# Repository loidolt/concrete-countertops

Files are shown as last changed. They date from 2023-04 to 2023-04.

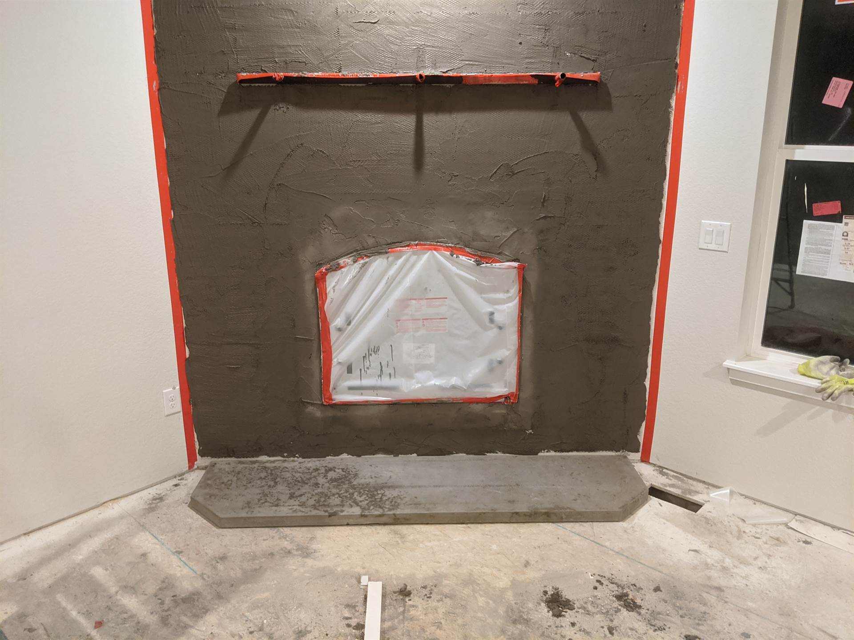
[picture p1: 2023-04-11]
images/ConcreteCountertops (8).jpg

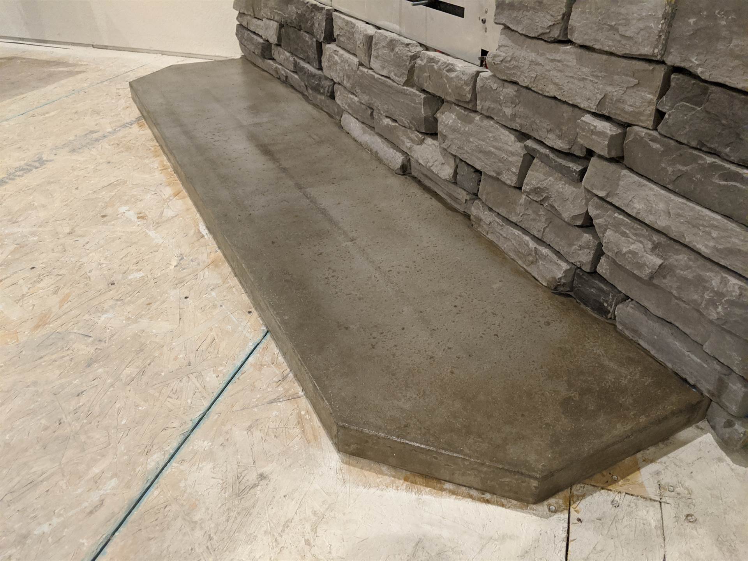
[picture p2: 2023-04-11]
images/ConcreteCountertops (5).jpg

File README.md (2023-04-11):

---
published: true
status: complete
date: 11/17/2019
tags: other, housing
description: The touch and go experience of pouring our entire house's concrete countertops.
slug: concrete-countertops
---

# Concrete Countertops

The touch and go experience of pouring our entire house's concrete countertops.

## Table of Contents

- [Concrete Countertops](#concrete-countertops)
  - [Table of Contents](#table-of-contents)
  - [General Info](#general-info)
  - [Process](#process)
  - [Problems](#problems)
    - [Molds](#molds)
    - [Mix](#mix)
    - [Pouring](#pouring)
  - [Recovery](#recovery)
  - [Finish](#finish)
  - [Technologies](#technologies)

## General Info

When we built our house in Monument, CO, we decided to do concrete countertops because we liked the industrial look and it saved us a lot of money on granite (plus let's be honest, I just like to make stuff.) Pouring our own also allowed us to do some cool stuff like a drain slope section of the kitchen sink area to direct dripping hand water back into the sink.

That said, this project very nearly didn't work out for a few reasons.

## Process

Designing these and making the forms was relatively easy. They are essentially just large rectangles of a specific size with foam knockouts for the sinks and faucets. The foam knockouts were cut on the CNC and were modeled directly from the manufacturer's technical drawings for each item.

Forms were made from melamine and the foam pieces were located and siliconed into place. We also used a silicone round-over kit to create a fillet on the resultant concrete edges.

A rebar substructure was created for each mold and set aside to be placed into each mold after it was half-way filled. Concrete was mixed per the directions on the bag (more on this in the "problems" section) with some fiberglass additive mixed in for edge strength and the molds were poured/packed.

## Problems

Here's the good stuff, also known as "how to not have a terrible time and almost ruin your entire project" as we did.

### Molds

If you need more than one base layer sheet of melamine as we did for the island countertop, be sure to seal the edges of the melamine before assembly, and then seal the joint between pieces after assembly. Failure to do so will result in the edge of the melamine absorbing water and expanding, creating a divot in your finished surface.

Check your knockout placement as many times as you can muster, check it based on the 3d model, check it based on the hardware, and triple-check it based on the real life cabinet layout. We discovered after pouring the island countertop that the sink was a couple of inches too far to one side. We then had to dig up concrete that was already setting and move the knockouts over, not fun.

### Mix

Mix the concrete at least twice as wet as the bag says if you are using Quikrete Concrete Countertop Mix. I know all the guidance for concrete says to mix it as dry as possible for best strength, we aren't trying to build a bridge here, you'll be more than fine in the strength department. If you mix it to the directions on the bag be prepared to do a ton of filling and skim coating to get a smooth surface back.

### Pouring

Pour these one at a time, not all at once as we did. Take your time and use some source of vibration to knock out the air bubbles and settle fines. I also advise not doing this at sunset, in the cold, with just a couple of work lights.

## Recovery

Our countertops came out pretty rough, basically looking like a concrete sponge. Luckily, concrete is pretty forgiving in this aspect since you can apply essentially as many skim coats as your patience allows. So recovery for us was a long process of skimming, sanding, skimming, and sanding.

## Finish

We used Omega Concrete Countertop Sealer to add some toughness and prevent stains. I highly recommend this sealer and would use it again in a heartbeat. Easy to mix and apply durable, and heat resistant. We did find, at least in our climate with the house kept at about 65 degrees, that it took a little longer to set than we expected and it did add a slightly green tinge to the concrete.

## Technologies

- Sketchup

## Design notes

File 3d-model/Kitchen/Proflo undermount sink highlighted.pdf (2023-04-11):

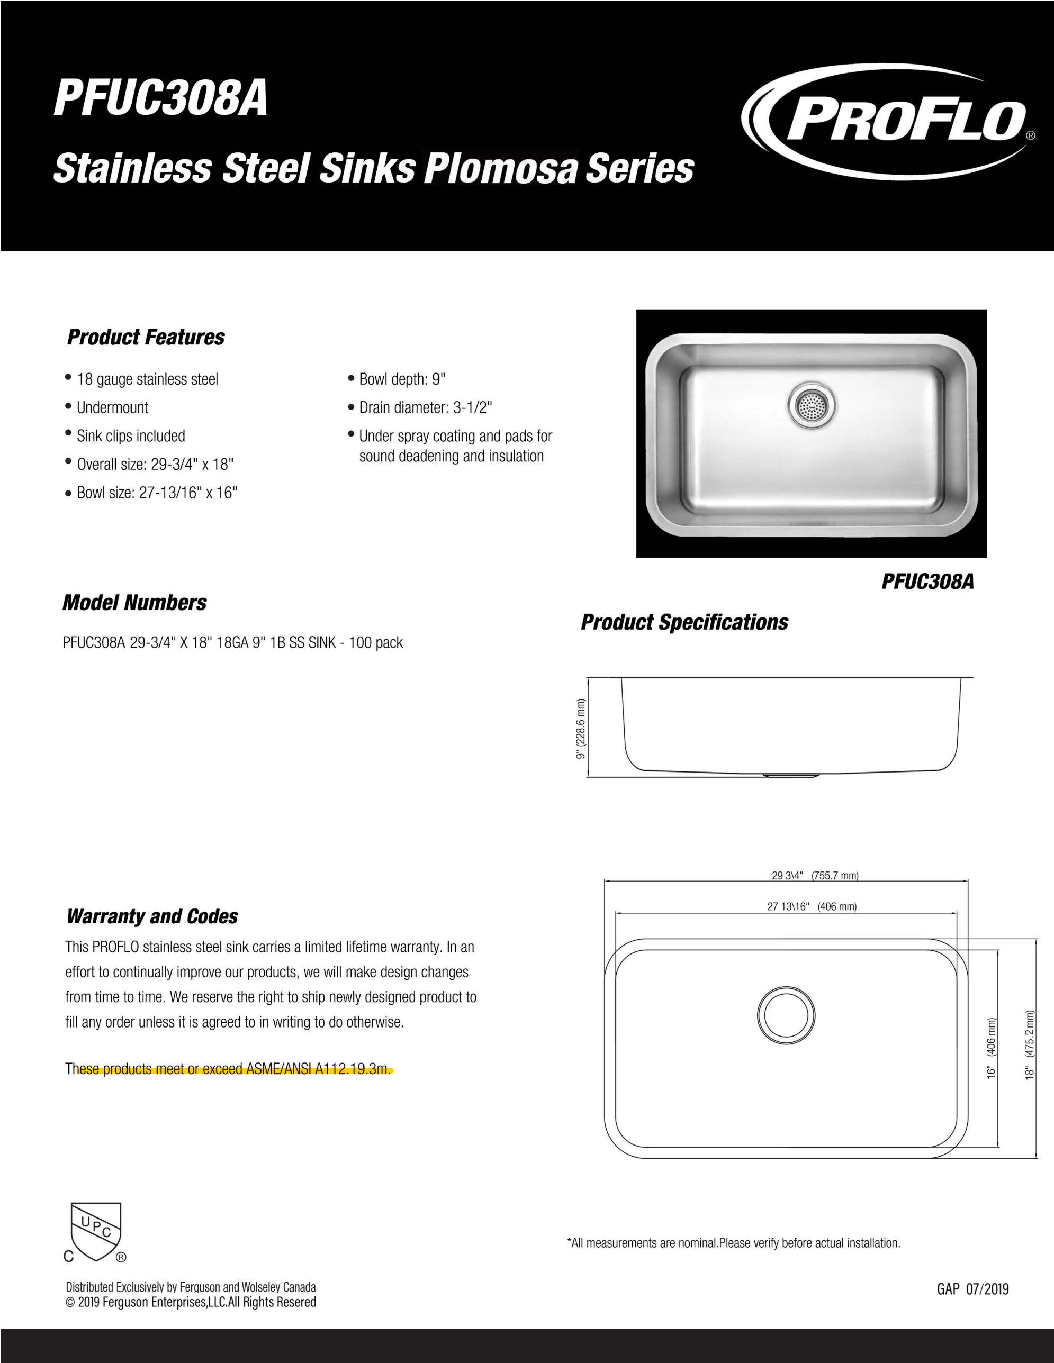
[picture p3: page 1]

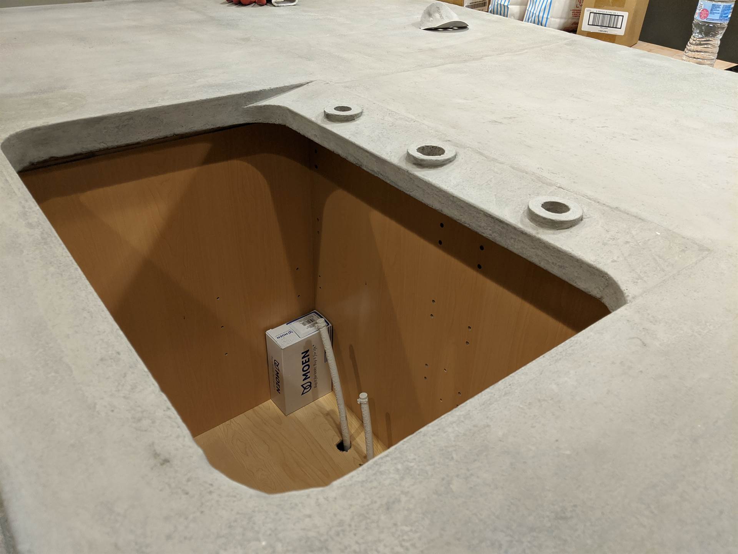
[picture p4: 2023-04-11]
images/ConcreteCountertops (2).jpg

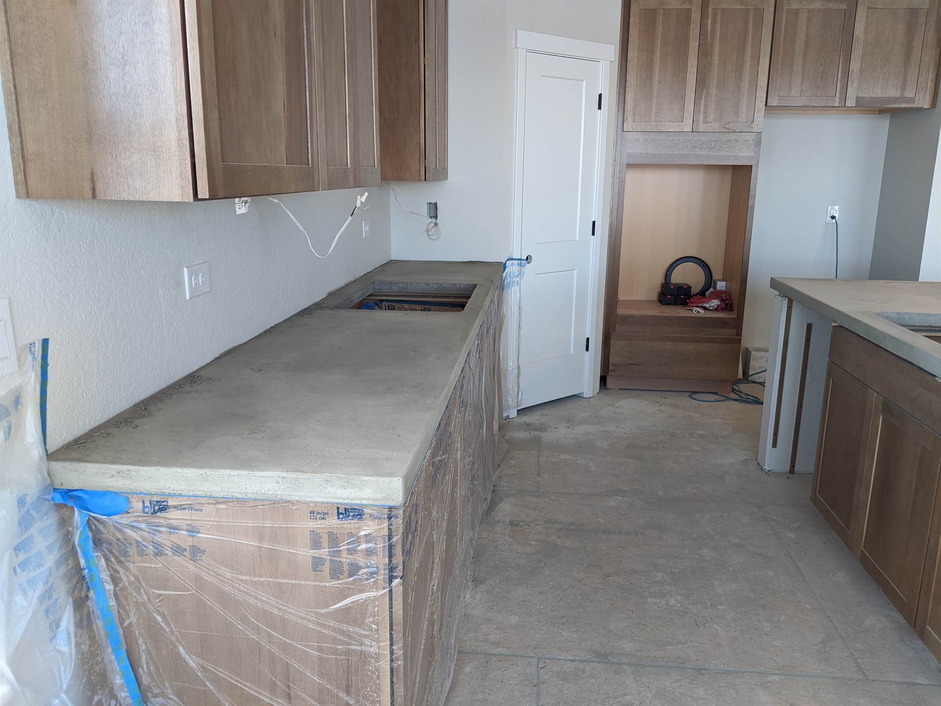
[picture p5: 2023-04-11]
images/ConcreteCountertops (11).jpg

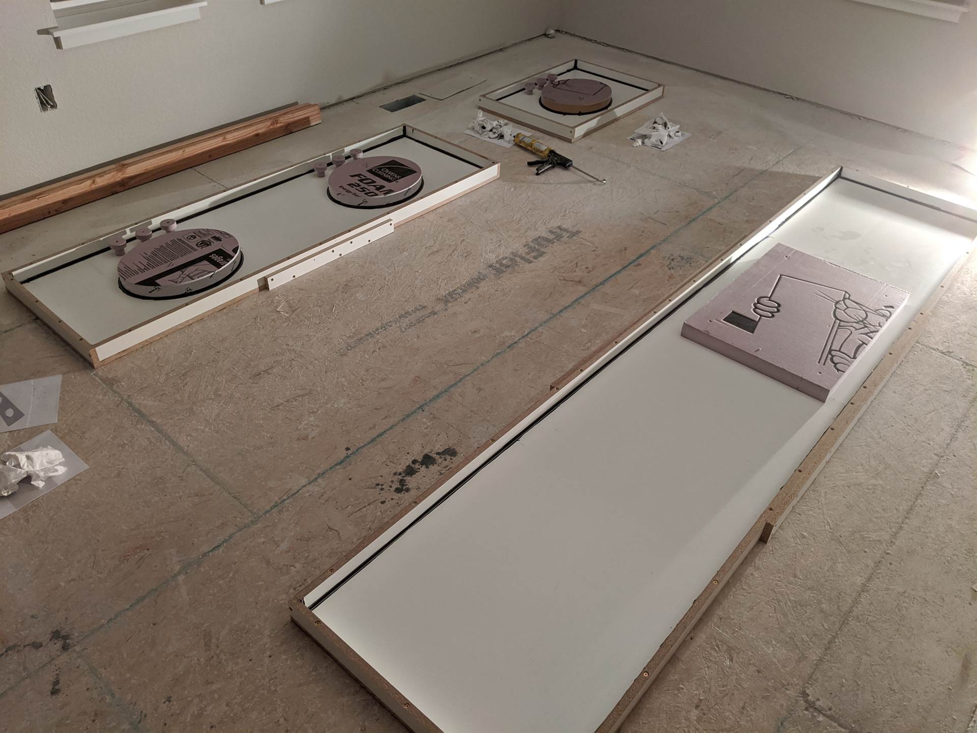
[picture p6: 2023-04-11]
images/ConcreteCountertops (7).jpg

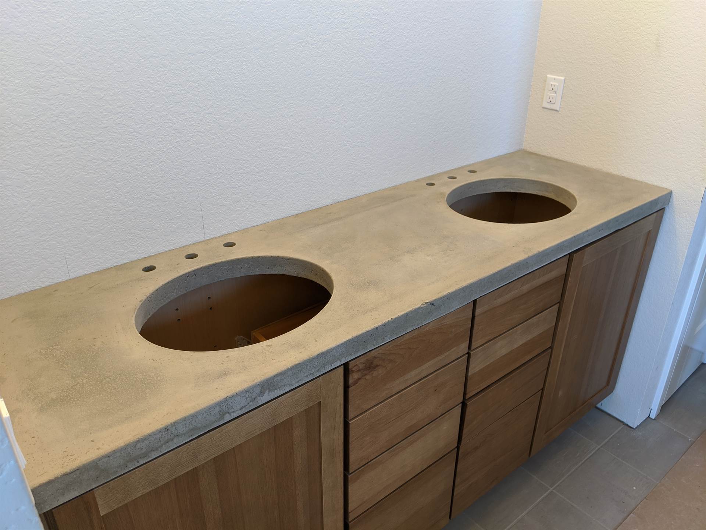
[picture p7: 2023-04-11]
images/ConcreteCountertops (1).jpg

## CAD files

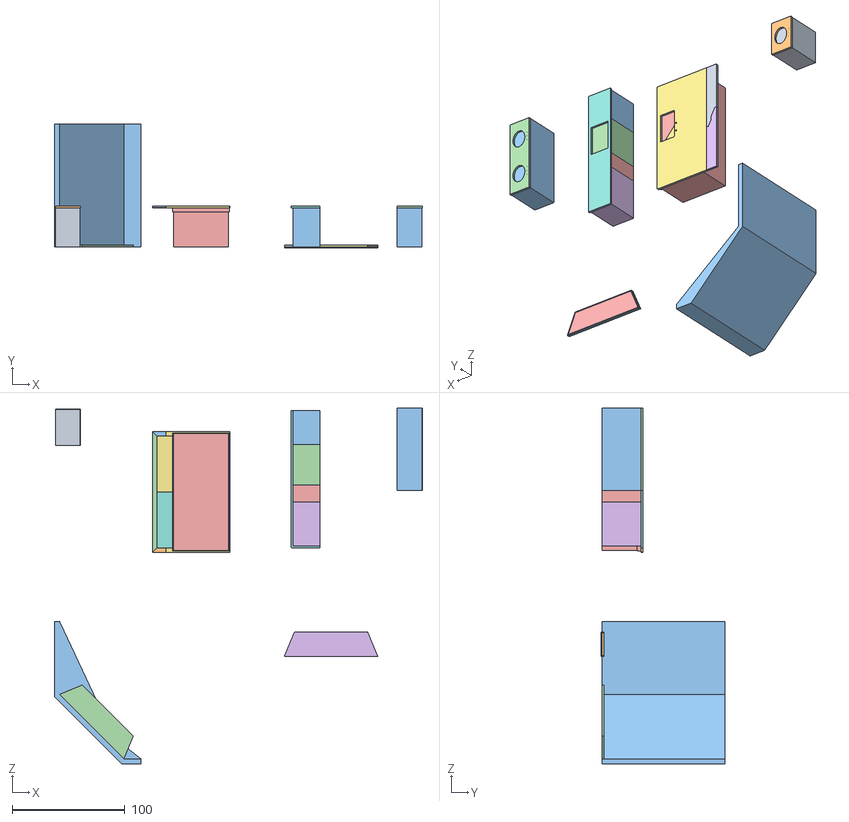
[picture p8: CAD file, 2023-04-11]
3d-model/ConcreteCountertops.obj
326.0 x 109.9 x 315.1
Mesh1 Cabinet_part1 GuestBath1 Model
Mesh2 Concrete_part_1_1 GuestBath1 Model
Mesh3 WallPart1 Hearth1 Model
Mesh4 Hearth_part1 Hearth1 Model
Mesh5 HearthStraight_part1 Hearth1 Model
Mesh6 FormBase_sheet1 Hearth1 Model
Mesh7 SideFront_sheet1 Hearth1 Model
Mesh8 SideBack_sheet1 Hearth1 Model
Mesh9 Side_sheet1 Hearth1 Model
Mesh10 Side_sheet2 Hearth1 Model
Mesh11 BSM30WD_part1 Group1 Kitchen1 Model
Mesh12 RPB36_part1 Group1 Kitchen1 Model
Mesh13 BL15_L_part1 Group1 Kitchen1 Model
Mesh14 B39_part1 Group1 Kitchen1 Model
Mesh15 Island_part_1_1 Kitchen1 Model
Mesh16 CountertopLarge_part_1_1 Kitchen1 Model
Mesh17 IslandPanelLower2_sheet1 Kitchen1 Model
Mesh18 IslandPanelLower1_sheet1 Kitchen1 Model
Mesh19 CounterPanelLong_sheet1 Kitchen1 Model
Mesh20 CounterPanelShort_sheet1 Kitchen1 Model
Mesh21 Cabinets_part1 Kitchen1 Model
Mesh22 WoodEdgeLeft_part_1_1 Kitchen1 Model
Mesh23 IslandPanelLower3_sheet1 Kitchen1 Model
Mesh24 IslandPanelLower3_sheet2 Kitchen1 Model
Mesh25 WoodEdgeRight_part_1_1 Kitchen1 Model
Mesh26 CherryTrimShort_1_1 Kitchen1 Model
Mesh27 CherryTrimShort_1_2 Kitchen1 Model
Mesh28 CherryTrimLong_1_1 Kitchen1 Model
Mesh29 Wedges1 Kitchen1 Model
Mesh30 IslandPanelTop1_sheet1 Kitchen1 Model
Mesh31 IslandPanelTop2_sheet1 Kitchen1 Model
Mesh32 IslandPanelTop3_sheet1 Kitchen1 Model
Mesh33 CounterPanelLong_sheet2 Kitchen1 Model
Mesh34 CounterPanelShort_sheet2 Kitchen1 Model
Mesh35 Cabinets_part_1_1 MasterBath1 Model
Mesh36 Concrete_part_2_1 MasterBath1 Model

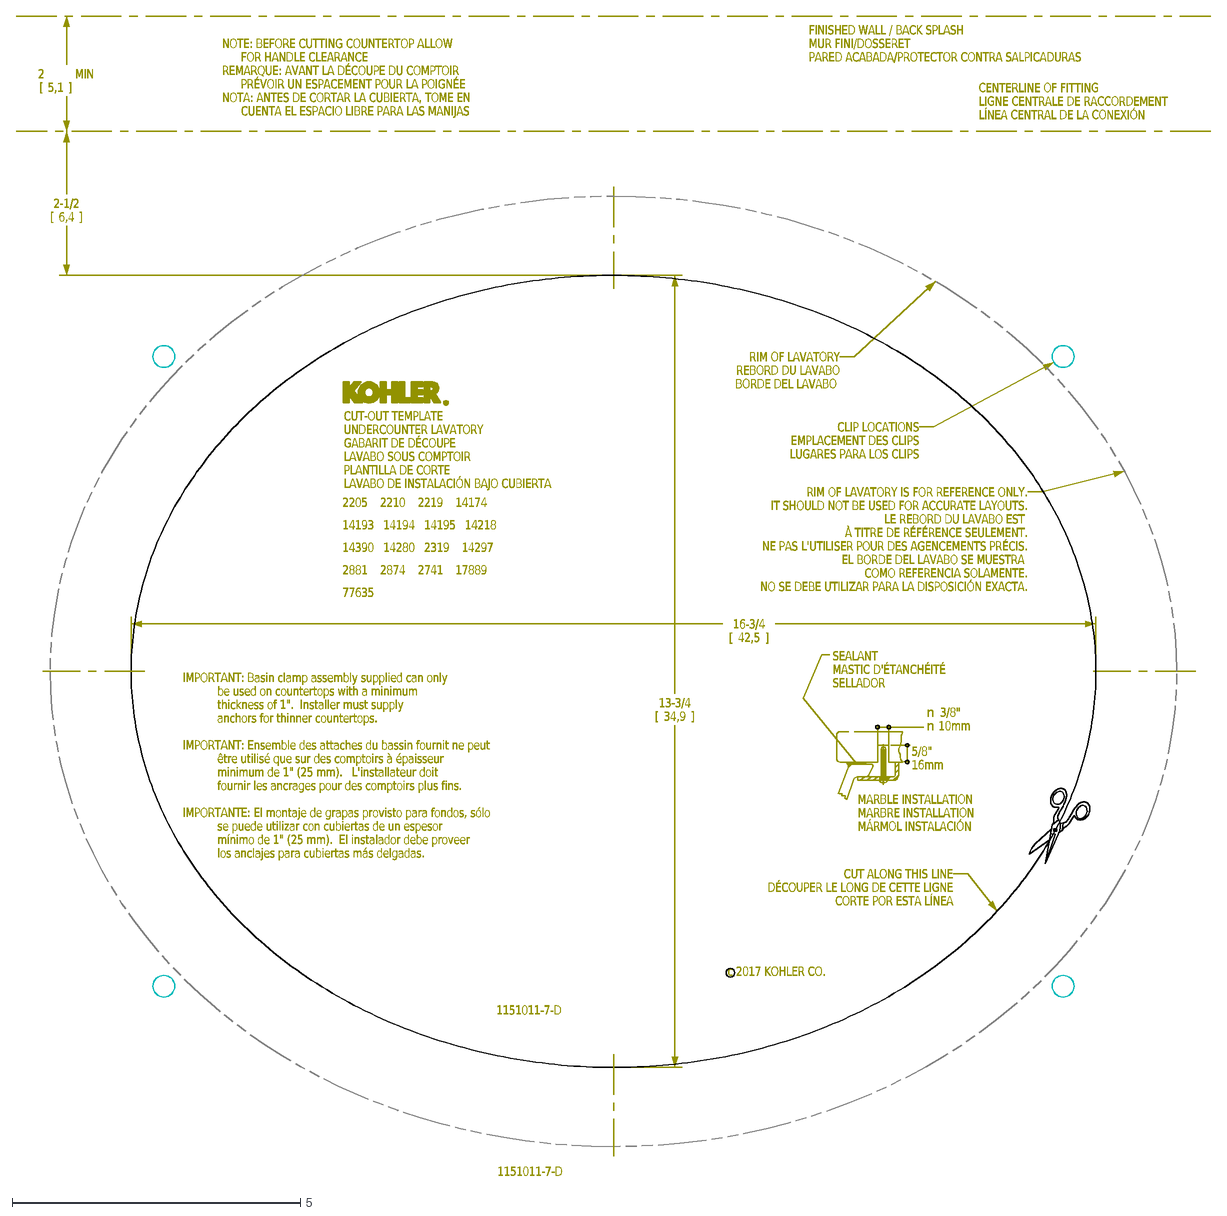
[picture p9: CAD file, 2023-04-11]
3d-model/GuestBath/1151011_7_d.dxf
13-3/4
[
34,9
]
16-3/4
42,5
2-1/2
6,4
2
MIN
5,1
CUT-OUT TEMPLATE
UNDERCOUNTER LAVATORY
GABARIT DE DÉCOUPE
LAVABO SOUS COMPTOIR
PLANTILLA DE CORTE
LAVABO DE INSTALACIÓN BAJO CUBIERTA
FINISHED WALL / BACK SPLASH
MUR FINI/DOSSERET
PARED ACABADA/PROTECTOR CONTRA SALPICADURAS
NOTE: BEFORE CUTTING COUNTERTOP ALLOW
FOR HANDLE CLEARANCE
REMARQUE: AVANT LA DÉCOUPE DU COMPTOIR
PRÉVOIR UN ESPACEMENT POUR LA POIGNÉE
NOTA: ANTES DE CORTAR LA CUBIERTA, TOME EN
CUENTA EL ESPACIO LIBRE PARA LAS MANIJAS
IMPORTANT: Basin clamp assembly supplied can only
be used on countertops with a minimum
thickness of 1". Installer must supply
anchors for thinner countertops.
IMPORTANT: Ensemble des attaches du bassin fournit ne peut
être utilisé que sur des comptoirs à épaisseur
minimum de 1" (25 mm). L'installateur doit
fournir les ancrages pour des comptoirs plus fins.
IMPORTANTE: El montaje de grapas provisto para fondos, sólo
se puede utilizar con cubiertas de un espesor
mínimo de 1" (25 mm). El instalador debe proveer
los anclajes para cubiertas más delgadas.
CENTERLINE OF FITTING
LIGNE CENTRALE DE RACCORDEMENT
LÍNEA CENTRAL DE LA CONEXIÓN
2205 2210 2219 14174
14193 14194 14195 14218
14390 14280 2319 14297
2881 2874 2741 17889
77635
5/8"
16mm
MARBLE INSTALLATION
MARBRE INSTALLATION
MÁRMOL INSTALACIÓN
SEALANT
MASTIC D'ÉTANCHÉITÉ
SELLADOR
3/8"
10mm
1151011-7-D
c 2017 KOHLER CO.
CUT ALONG THIS LINE
DÉCOUPER LE LONG DE CETTE LIGNE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

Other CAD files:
3d-model/GuestBath/2210pln.dxf
3d-model/MasterBath/2210pln.dxf
3d-model/ConcreteCountertops.skp
3d-model/GuestBath/GuestBath.skp
3d-model/Hearth/Hearth.skp
3d-model/Kitchen/Kitchen.skp
3d-model/MasterBath/MasterBath.skp

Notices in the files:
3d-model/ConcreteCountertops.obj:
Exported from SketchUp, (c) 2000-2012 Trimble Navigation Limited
